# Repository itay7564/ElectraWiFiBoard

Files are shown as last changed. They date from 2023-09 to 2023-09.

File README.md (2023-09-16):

# ElectraWiFiBoard

A PCB which enables connecting an Electra air conditioner to internet using a Wemos D1 mini esp8266 module

The circuit is based on the [ElectraWiFi](https://github.com/giladger/ElectraWifi) repository by [giladger](https://github.com/giladger) which contains code for this project

I designed it using KiCad

# Bill of Materials
Connector - J1 - 8 pin DIN connector [footprint from CUI MD-80SM](https://www.cuidevices.com/product/interconnect/connectors/din-connectors/md-80sm)

WiFi Module - U1 - WeMos D1 mini

LED - D1-D4 - 3mm pth LED

IR Reciever - U2 - TSOP41xx

Buzzer - BZ1 - 12mm buzzer

Resistor - R4 - PTH resistor 100 ohm

Resistors - R1-R3 - PTH resistor 1K ohm

# Photos
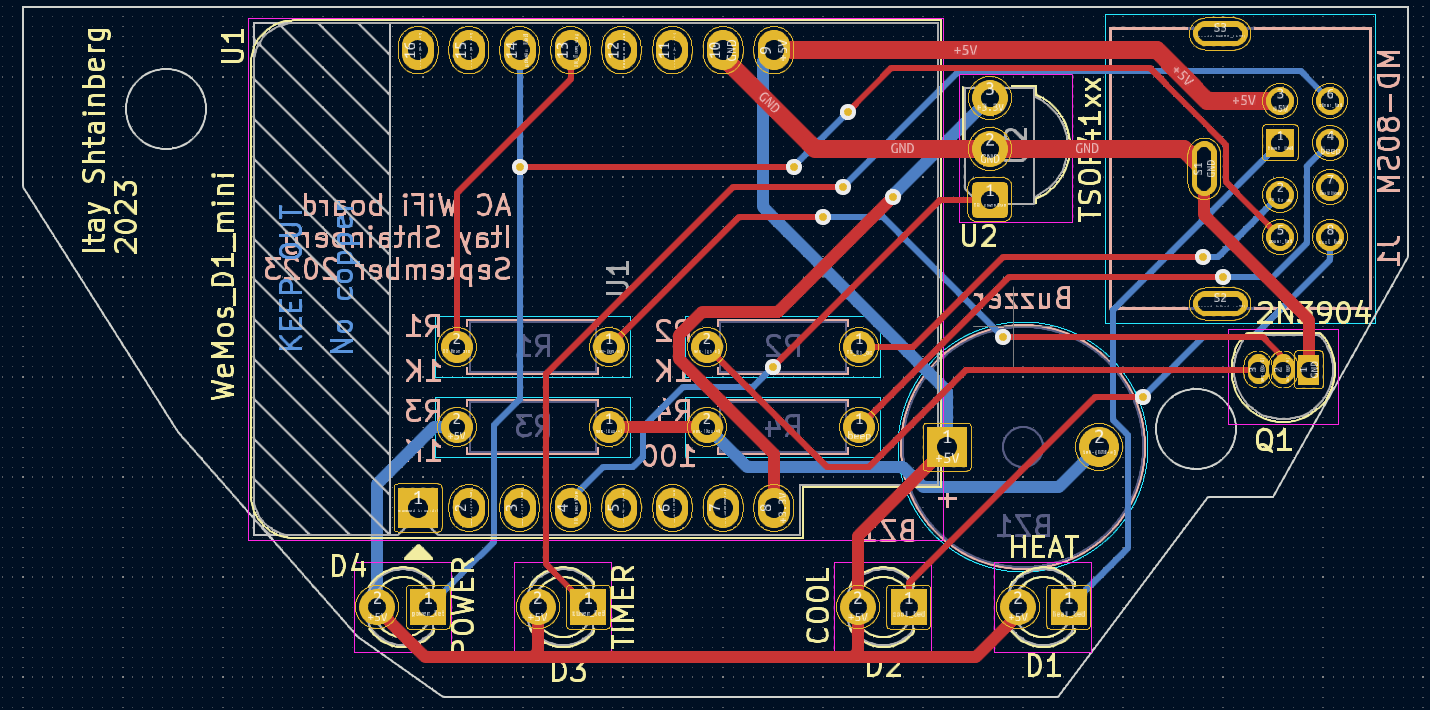
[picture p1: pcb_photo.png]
PCB design


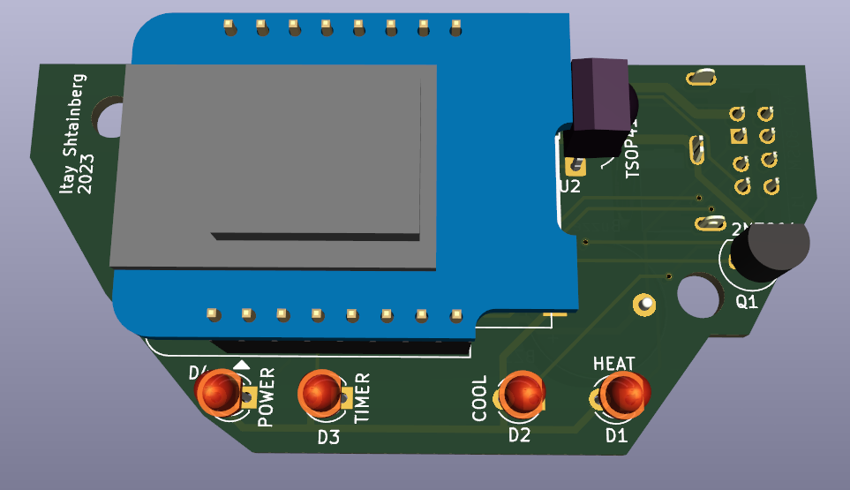
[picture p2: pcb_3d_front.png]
PCB 3d front


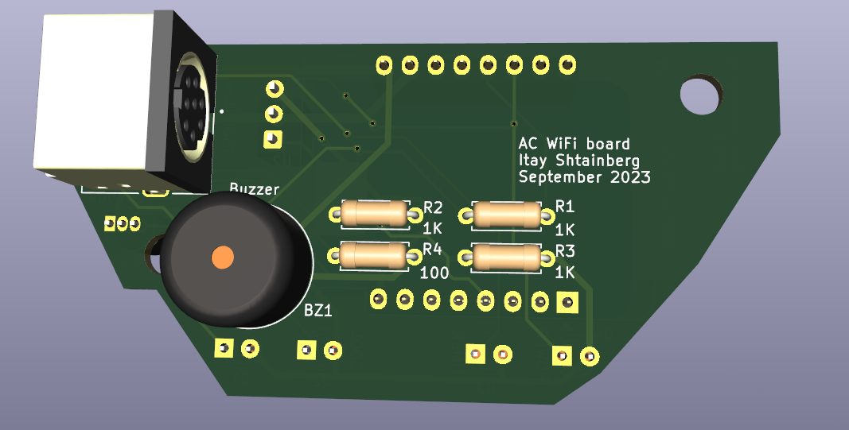
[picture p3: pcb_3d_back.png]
PCB 3d back


# Credits

Thanks to Guy Eshel who prompted the design and helped with measurments 

Thanks to [giladger](https://github.com/giladger) and the contributors of the [ElectraWiFi](https://github.com/giladger/ElectraWifi) repo which contains the code for this project

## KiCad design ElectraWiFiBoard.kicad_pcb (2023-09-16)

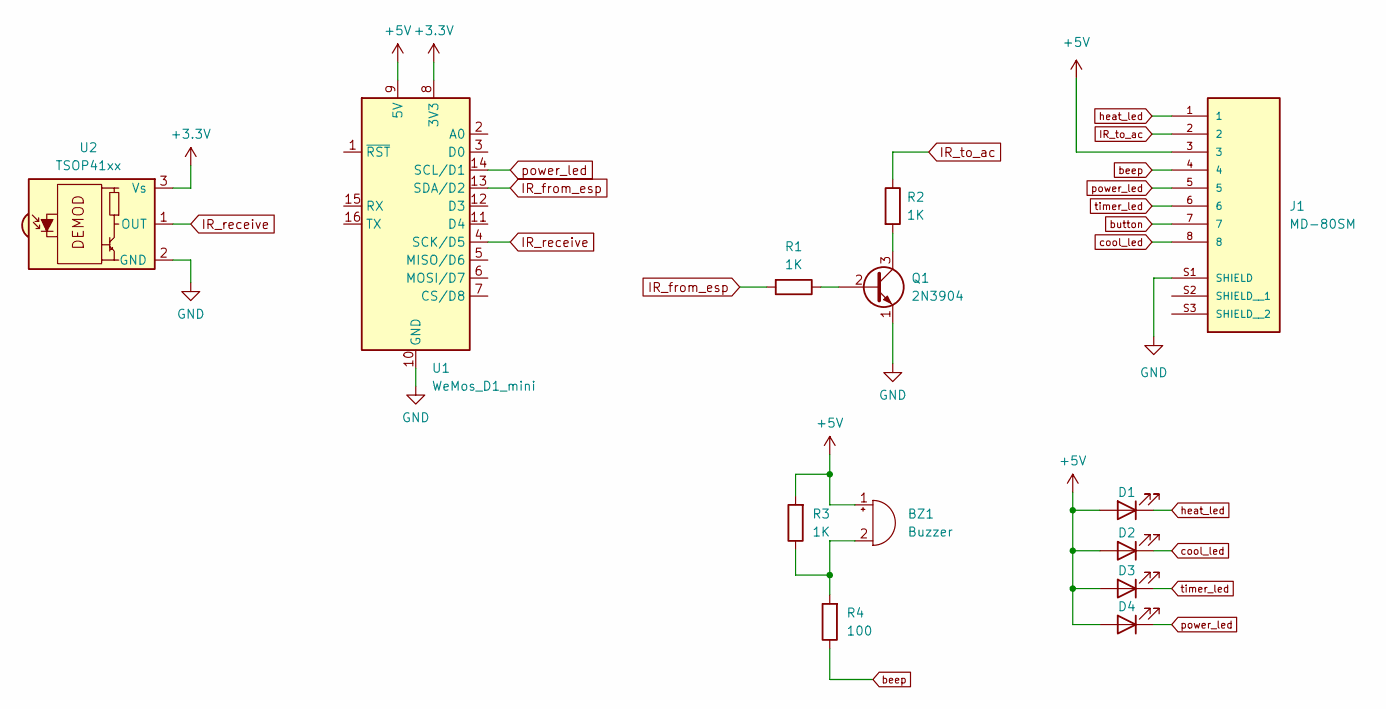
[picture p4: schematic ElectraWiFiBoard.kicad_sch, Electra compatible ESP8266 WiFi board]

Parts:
BZ1: Buzzer; Buzzer_12x9.5RM7.6
D1: HEAT; LED_D3.0mm
D2: COOL; LED_D3.0mm
D3: TIMER; LED_D3.0mm
D4: POWER; LED_D3.0mm
J1: MD-80SM; CUI_MD-80SM; PARTREV 02/18/2022
Q1: 2N3904; TO-92_Inline
R1, R2, R3: 1K; R_Axial_DIN0207_L6.3mm_D2.5mm_P7.62mm_Horizontal
R4: 100; R_Axial_DIN0207_L6.3mm_D2.5mm_P7.62mm_Horizontal
U1: WeMos_D1_mini; WEMOS_D1_mini_light
U2: TSOP41xx; Vishay_MOLD-3Pin

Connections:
+3.3V: U1.8 (3V3), U2.3 (Vs)
+5V: BZ1.1 (-), D1.2 (A), D2.2 (A), D3.2 (A), D4.2 (A), J1.3, R3.2, U1.9 (5V)
GND: J1.S1 (SHIELD), Q1.1 (E), U1.10 (GND), U2.2 (GND)
IR_from_esp: R1.2, U1.13 (SDA/D2)
IR_receive: U1.4 (SCK/D5), U2.1 (OUT)
IR_to_ac: J1.2, R2.1
unnamed: BZ1.2 (+), R3.1, R4.2
unnamed: Q1.2 (B), R1.1
unnamed: Q1.3 (C), R2.2
beep: J1.4, R4.1
button: J1.7
cool_led: D2.1 (K), J1.8
heat_led: D1.1 (K), J1.1
power_led: D4.1 (K), J1.5, U1.14 (SCL/D1)
timer_led: D3.1 (K), J1.6

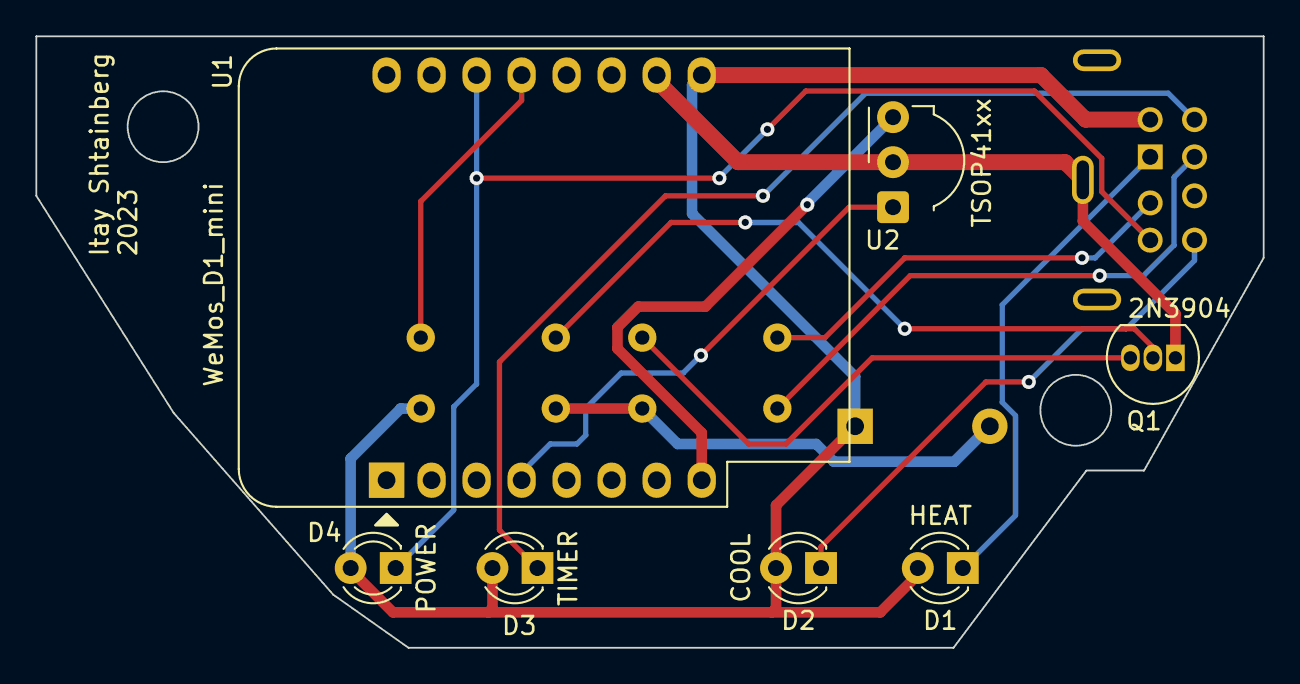
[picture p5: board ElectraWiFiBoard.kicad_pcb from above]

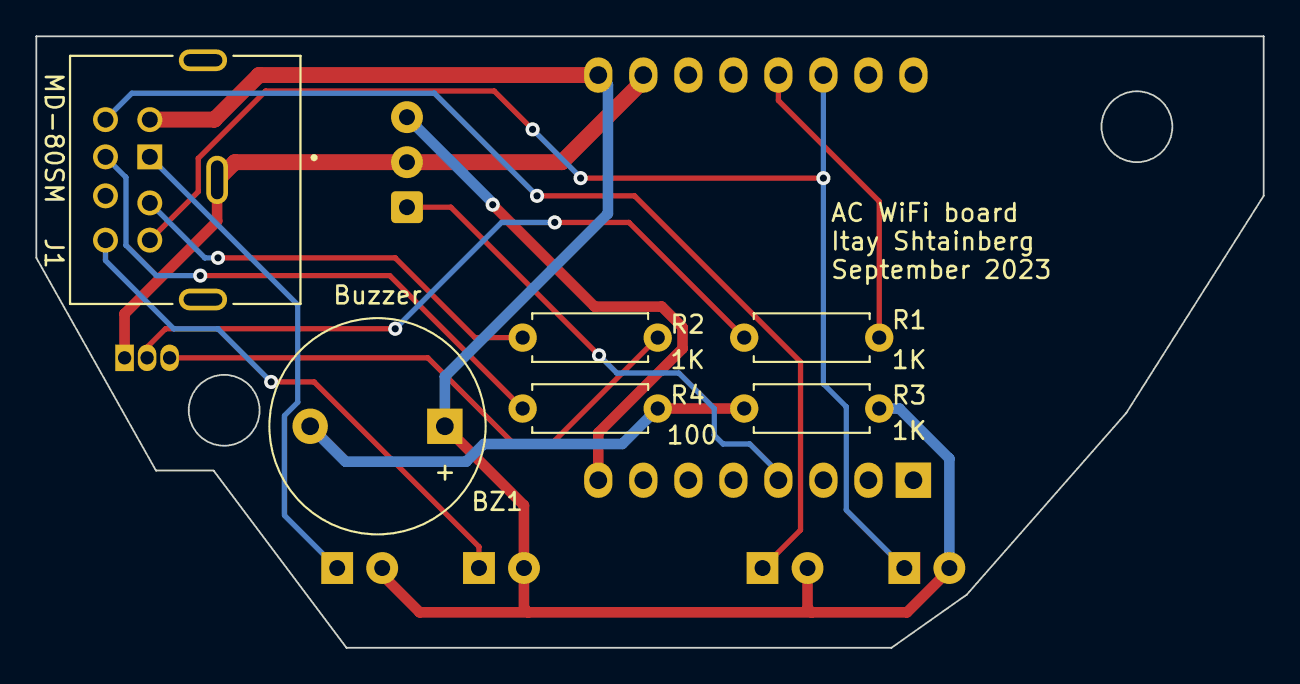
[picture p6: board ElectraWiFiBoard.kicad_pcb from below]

Board: 2 copper layers, 69.2 x 34.5 mm, 13 parts (6 on the bottom side), 14 nets.

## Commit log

2023-09-16 init commit
    [ElectraWiFi BOM.xlsx, ElectraWiFiBoard.kicad_pcb, ElectraWiFiBoard.kicad_sch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]
2023-09-16 remove gerbers
2023-09-16 remove untracked files
    [ElectraWiFi BOM.xlsx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]
